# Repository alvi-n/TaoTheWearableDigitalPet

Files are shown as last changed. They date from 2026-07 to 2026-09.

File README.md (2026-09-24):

# Tao - A Palm-Sized, Sensor-Driven Dynamic Digital Pet ⭐

Tao is a highly responsive, accessible companion device that uses an **accelerometer** much like on phones that detect orientation to switch from portrait to landscape mode. It also utilizes a **temperature sensor** and **haptic motors** that vibrate, which all triggers unique face animations.

Over the past few months, I've been seeing this unique hardware accessory called ["Starboy" by CREATURE](https://hesjustalittleguy.com/). It features a palm-sized digital pet that has a star-shaped form factor and a round screen in the middle with very expressive eyes. As you can probably tell by the title description, this project was heavily inspired by this. I was immediately captivated by the concept, but with the original product selling for around $150 to $300, I thought it felt like a great open-source, diy project.
> _"STARBOY perceives its environment through a camera, microphone, temperature sensor, and accelerometer. bring him into a loud environment and he gets anxious. Leave him in the cold and he shivers. Shake him and he gets dizzy and mad at you. give him a thumbs up to check the battery level, or flick him off if you feel like making him sad."_

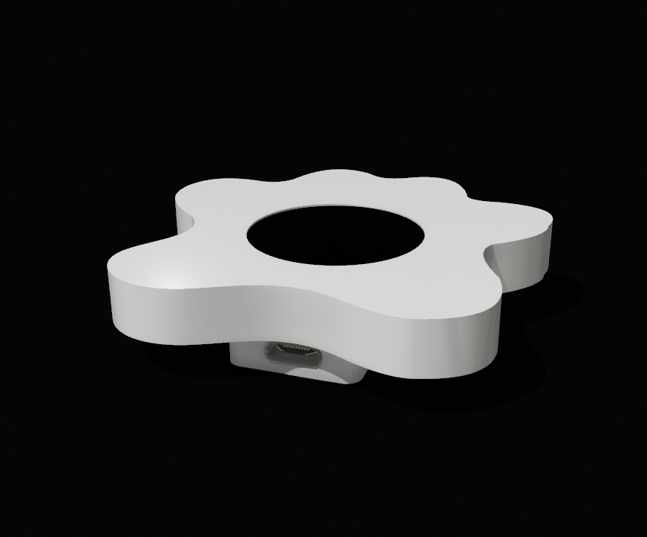
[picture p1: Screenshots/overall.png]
in cad

in my hand

## Hardware
- Seeed XIAO ESP32-S3
- Round GC9A01 SPI LCD
- LSM6DSL accelerometer (I2C)
- PCT2075D Temperature sensor (I2C)
- DRV2605L haptic driver (I2C, shared bus)
- 3.7V 300mAh LiPo battery

| Schematic | PCB | Render |
| ----- | ---- | ---- |
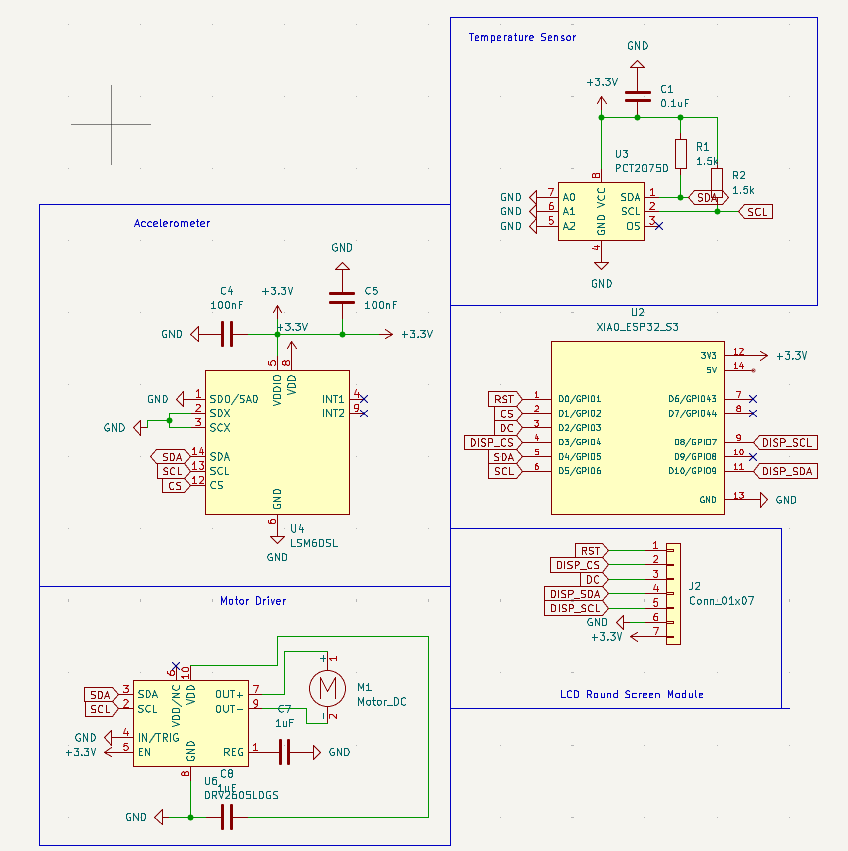
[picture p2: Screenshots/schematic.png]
"Schematic"
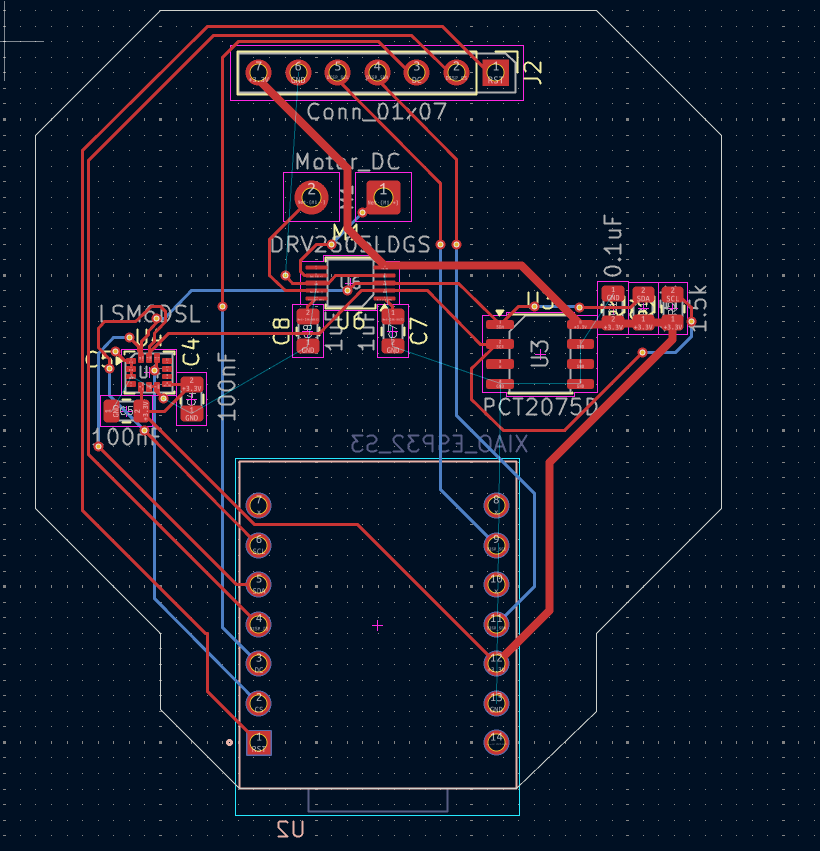
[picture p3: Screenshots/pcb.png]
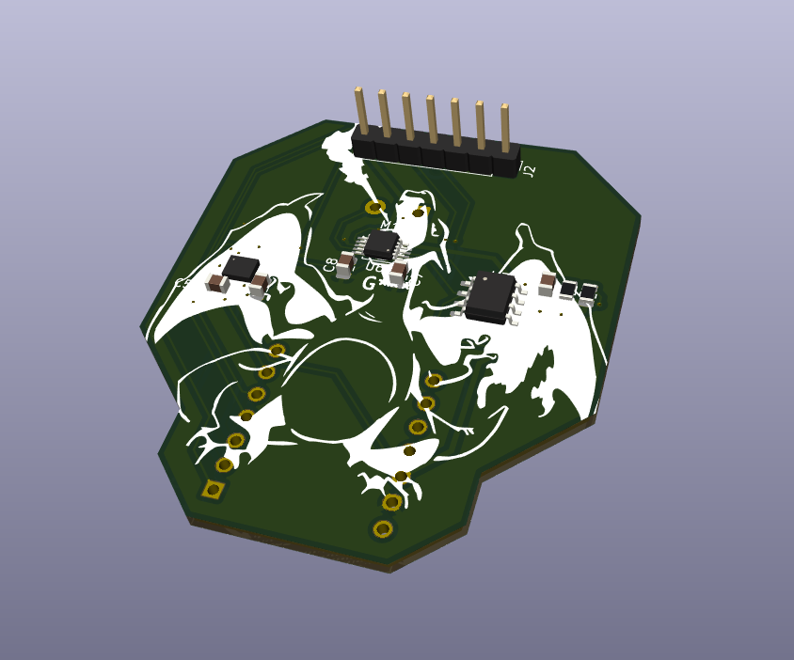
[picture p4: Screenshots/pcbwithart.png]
|  |  | 

## What It Does
- Two animated eyes are Tao's entire face
- An LSM6DSL accelerometer notes any change in motion in real time
  -The accelerometer reads the change in acceleration magnitude between frames and sorts it into still / moving / shake states
  - This is very similar to how your phone can detect if your screen is turned so you could watch videos fullscreen
- A haptic motor creates different unique haptic patterns depending on what Tao is going through
- Uses an ESP32-S3 development board to make power management easier

## Future Plans
- Add additional states for more interactions
- Use a deburring tool to round out all the edges
### If done again...
- NFC Chip - Originally this was supposed to have one but making a custom antenna was a diffcult process in such a limited space
- No modules - this means all power managment will have to be designed from scratch and same with the screen module
- Add more inputs like a microphone, camera, photoresistor, etc

BOM
| item | quantity | Link | Price |
| --- | --- | --- | --- |
| LSM6DSVQTR | 1 | lcsc | $12.04 |
| DRV2605LYZFR | 1 | lcsc | $6.75 |
| 10kΩ Resistor | 2 | lcsc | $0.03 |
| 100nF Capacitors | 4 | lscs | $0.34 |
| Seeed XIAO ESP32-S3 | 1 | https://www.seeedstudio.com/XIAO-ESP32S3-p-5627.html | $7.49 |
| 3.7V 300mAh 502035 LiPo | 1 | https://a.co/d/0aBGCeCJ | $9 |
| Round LCD Module GC9A01 | 1 | https://tinyurl.com/yj44nenv | $2 |
| LRA Haptic Motor| 1 | https://www.adafruit.com/product/1201 | $6 |
| PCT2075D Temperature Sensor| 1 | lcsc | $2.07 |
| Plastic Case | 3D - Printed |

> [!NOTE]
> Estimated Total Price: ~$75 USD with shipping 
> JLC PCBA charges an extra $21.77 for fees

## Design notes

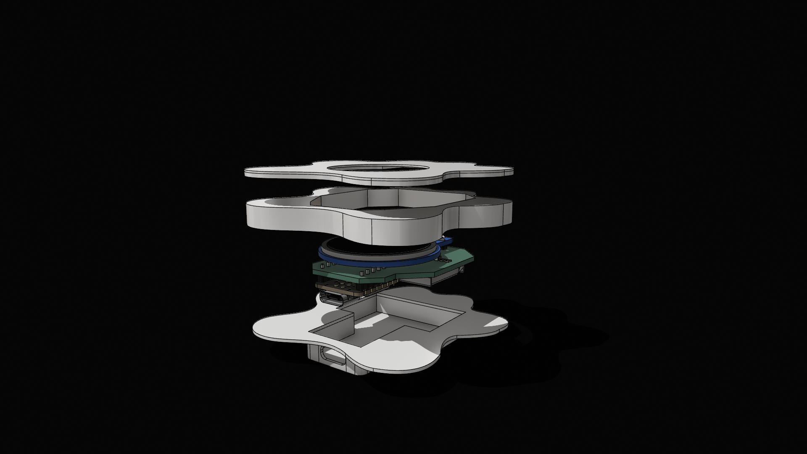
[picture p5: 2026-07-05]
Screenshots/fit.png

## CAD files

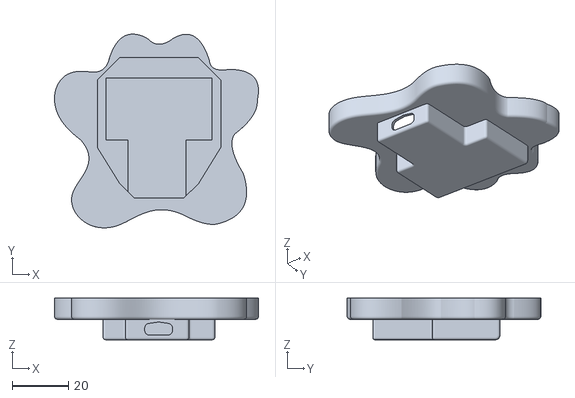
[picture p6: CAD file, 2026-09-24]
CAD/Folder 66.stl
72.7 x 69.0 x 14.8

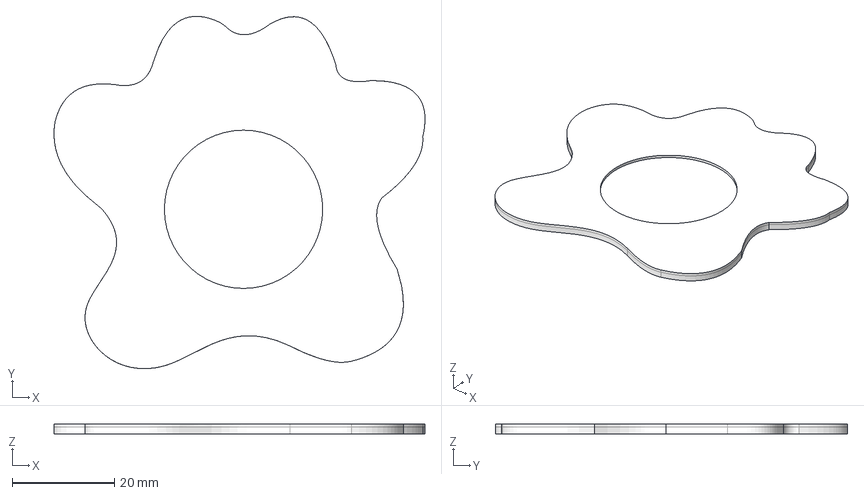
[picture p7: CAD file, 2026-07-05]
Production/topstar_v2.step
72.7 x 69.0 x 1.90 mm

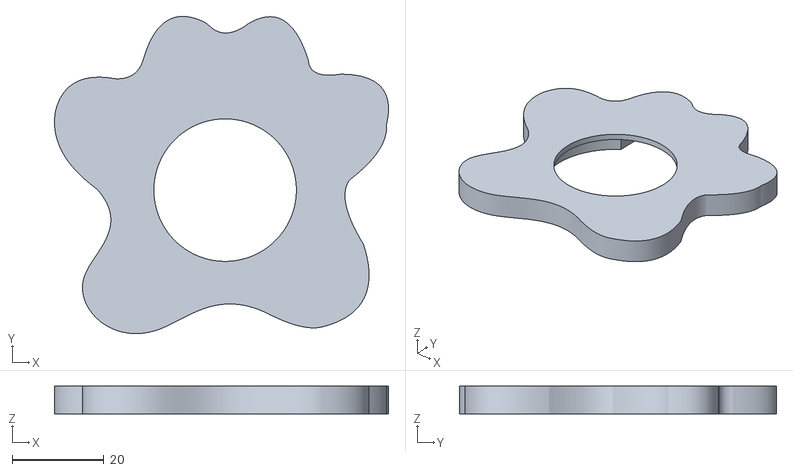
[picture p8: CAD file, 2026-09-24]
CAD/top_v2.stl
72.7 x 69.0 x 6.00

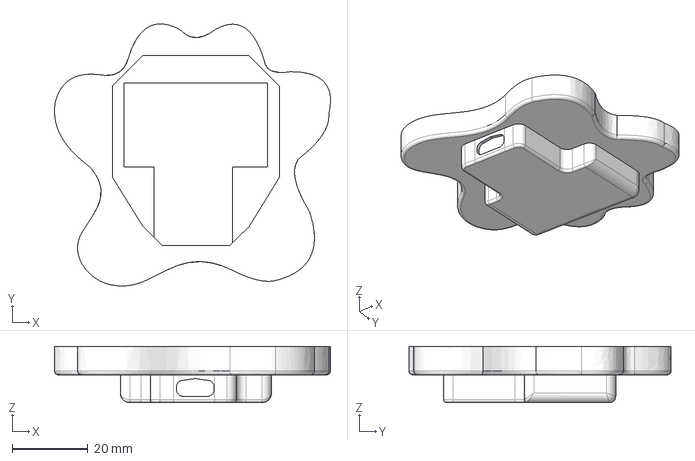
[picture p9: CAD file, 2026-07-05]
Production/bottomstar_v2.step
72.7 x 69.0 x 14.8 mm

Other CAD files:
Production/topstar.step

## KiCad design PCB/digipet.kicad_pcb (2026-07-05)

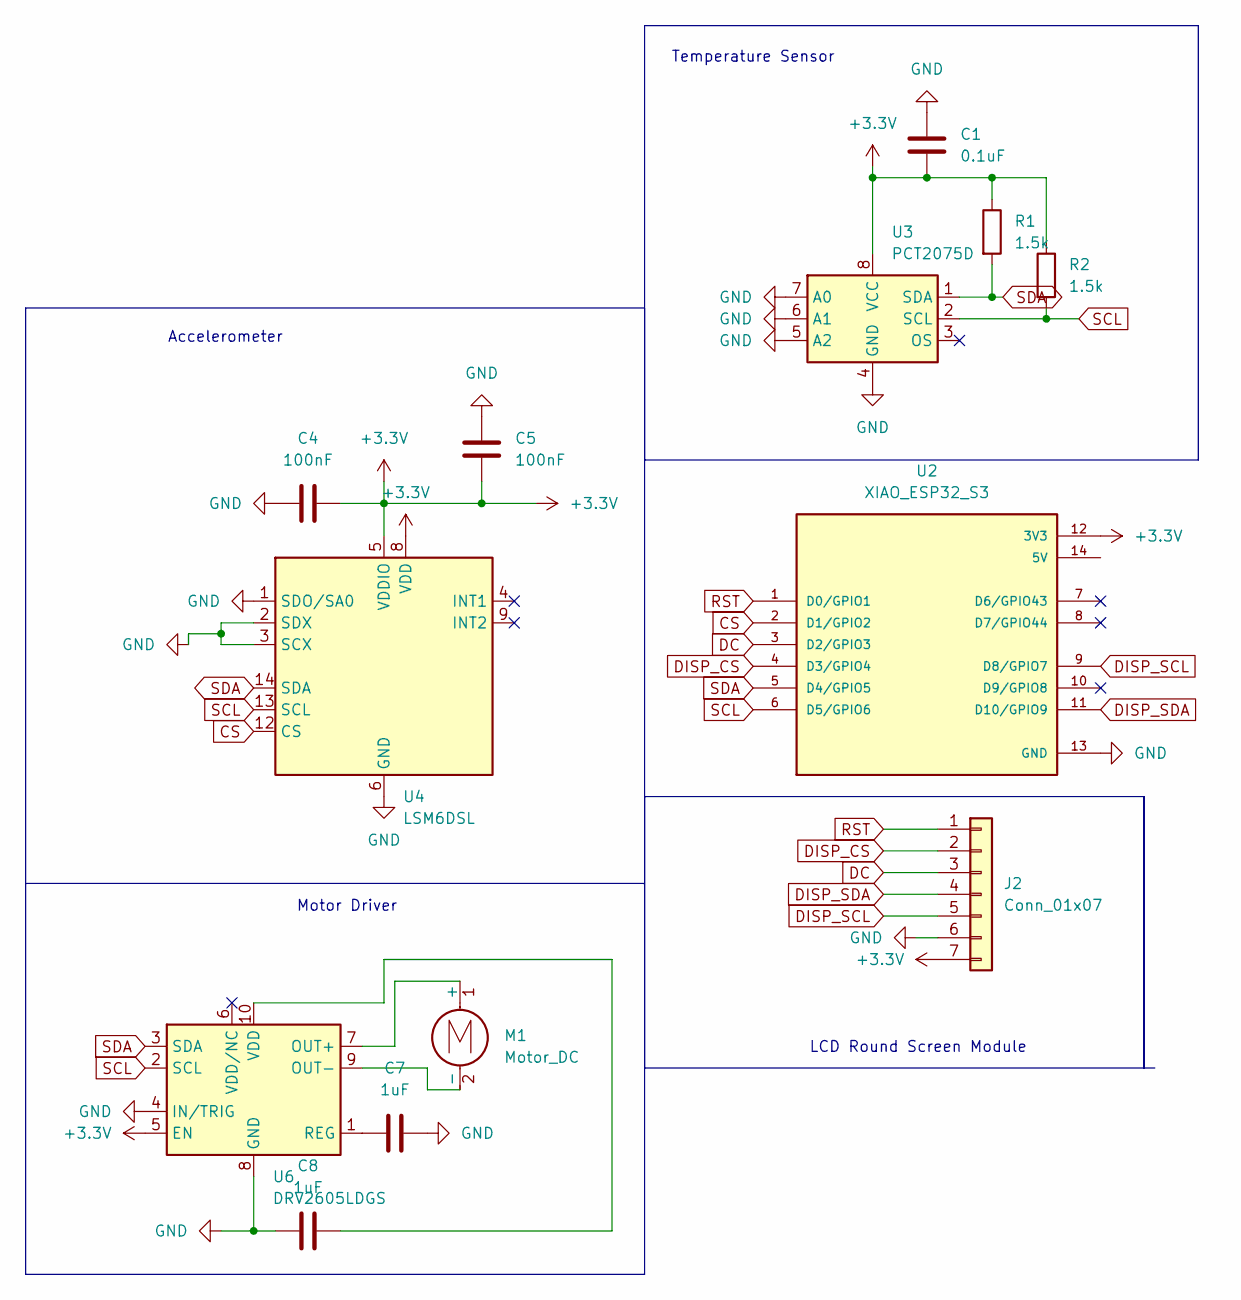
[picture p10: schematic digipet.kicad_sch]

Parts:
C1: 0.1uF; C_0805_2012Metric
C4, C5: 100nF; C_0805_2012Metric
C7, C8: 1uF; C_0805_2012Metric
J2: Conn_01x07; PinHeader_1x07_P2.54mm_Vertical
M1: Motor_DC; SolderWire-0.5sqmm_1x02_P4.6mm_D0.9mm_OD2.1mm
R1, R2: 1.5k; R_0805_2012Metric
U2: XIAO_ESP32_S3; MODULE_XIAO_ESP32_S3; PARTREV April 22nd, 2026
U3: PCT2075D; SO-8_3.9x4.9mm_P1.27mm
U4: LSM6DSL; LGA-14_3x2.5mm_P0.5mm_LayoutBorder3x4y
U6: DRV2605LDGS; VSSOP-10_3x3mm_P0.5mm

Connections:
+3.3V: C1.2, C4.2, C5.2, J2.7, R1.1, R2.1, U2.12 (3V3), U3.8 (VCC), U4.5 (VDDIO), U4.8 (VDD), U6.5 (EN)
CS: U2.2 (D1/GPIO2), U4.12 (CS)
DC: J2.3, U2.3 (D2/GPIO3)
DISP_CS: J2.2, U2.4 (D3/GPIO4)
DISP_SCL: J2.5, U2.9 (D8/GPIO7)
DISP_SDA: J2.4, U2.11 (D10/GPIO9)
GND: C1.1, C4.1, C5.1, C7.2, C8.1, J2.6, U2.13 (GND), U3.4 (GND), U3.5 (A2), U3.6 (A1), U3.7 (A0), U4.1 (SDO/SA0), U4.2 (SDX), U4.3 (SCX), U4.6 (GND), U4.7 (GND), U6.4 (IN/TRIG), U6.8 (GND)
unnamed: M1.1 (+), U6.7 (OUT+)
unnamed: M1.2 (-), U6.9 (OUT-)
unnamed: C7.1, U6.1 (REG)
unnamed: C8.2, U6.10 (VDD)
RST: J2.1, U2.1 (D0/GPIO1)
SCL: R2.2, U2.6 (D5/GPIO6), U3.2 (SCL), U4.13 (SCL), U6.2 (SCL)
SDA: R1.2, U2.5 (D4/GPIO5), U3.1 (SDA), U4.14 (SDA), U6.3 (SDA)

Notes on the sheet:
Motor Driver
Temperature Sensor
Accelerometer
LCD Round Screen Module

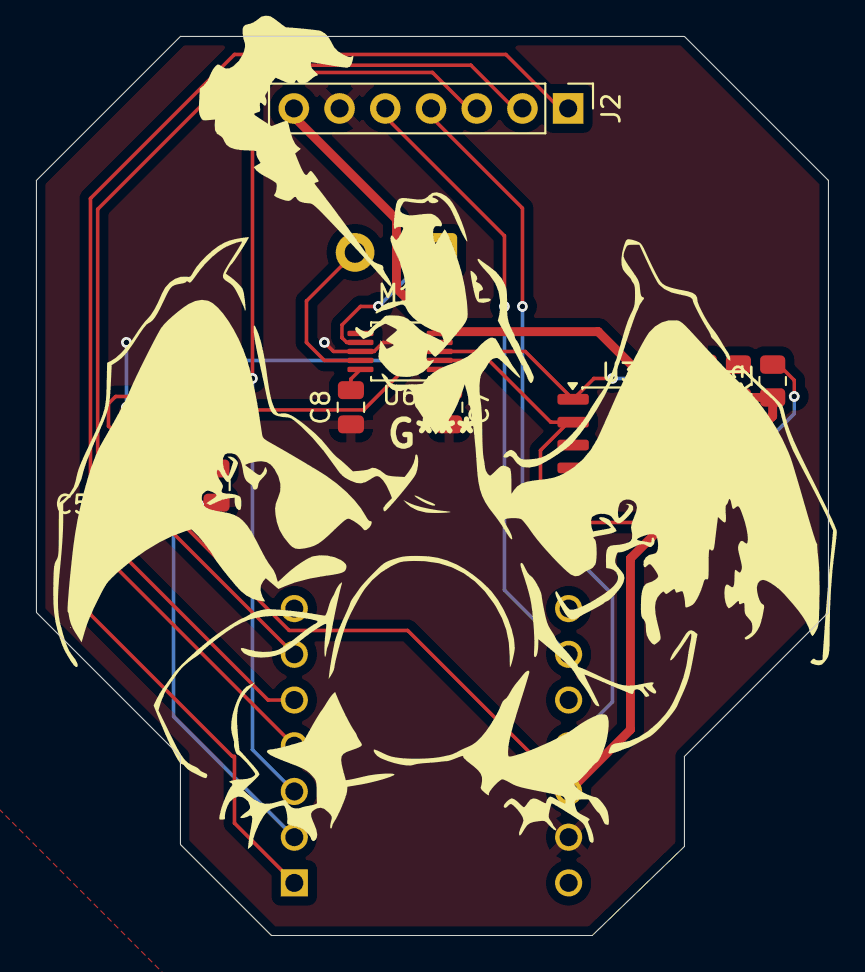
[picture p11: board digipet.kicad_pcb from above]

Board: 2 copper layers, 44.0 x 49.9 mm, 13 parts (1 on the bottom side), 14 nets.

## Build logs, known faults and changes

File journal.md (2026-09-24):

# Digital Pet PCB — Build Log

## No modules, everything on a PCB. *(1 hr)*

I've been seeing these digital pet accessories, similar to a Tamagotchi, on my feed a lot and the company selling these were listing them for ~$300 and I thought "I could definitely make this myself". These things interact with the environment with some basic sensors which gives the face a signal to change its animation.

Turns out it's wayy harder than I thought to make myself, considering my only hardware project I've made was a macropad.

There is a lot of pieces and I obviously haven't built anything like this ever. Instead of adding modules that hook up to a breadboard, I realized that all of those parts can be added to the PCB itself, and it all starts with the chip.

I looked for the best chip for each of the different features and looked at the schematic for each. The only chip with a datasheet that actually made sense was for the battery charger, the rest... it took a bit more work.

Anyways tomorrow, I'm planning on trying to finish the schematics, so make sure to follow!

<p align="center">
  
</p>

---

## Tao Now Has an Accelerometer, NFC Reader, and a Temperature Sensor *(2 hr 19 min)*

`all powered by the xiao esp-32 s3`

- I never realized how powerful **development boards** are. Last session, I took an hour trying to figure out how to make a buck converter, battery charger, and an external USB-C connector — turns out the XIAO board does all of that for me.
- Now instead of focusing my time on the power management side of my project, which was really confusing for me, I could now focus on adding additional **fun** elements to my project such as a haptic motor and temperature sensor.
- Overall this project has been pretty fun so far — next step is working on the PCB layout and thinking about the shape of my digital pet.

<p align="center">
  
</p>

---

## A little bit of this and a little bit of that. *(51 min)*

Today I started on my actual PCB design and turns out it's harder than I thought. My schematic is like a maze, some lines in my schematic going two directions. Figuring out the best way to put everything is definitely a challenge.

- Tomorrow, I'll start working on the edge cuts first and try to get 50% of the PCB wired.

<p align="center">
  
</p>

---

## Outlining my PCB *(30 min)*

Not much was done in these 30 minutes, just imported a drawing of the shape of the pet.

<p align="center">
  
  
</p>

---

## PCB routing - continued *(1 hr 21 min)*

So far I believe I've set up the temperature sensor, motor driver, and accelerometer well — and by that, I mean just the capacitors and resistors.

I'm planning on putting the ESP32 on the back side where I'll also keep the battery so it doesn't interfere with the LCD screen. This has been quite fun so far.

<p align="center">
  
</p>

---

## Honestly, I do not think I can get past the cut *(3 hr 6 min)*

Spent too long trying to figure out how to make my own NFC chip antenna, and for the time I'm trying to rush this project, I don't think I can.

- I think I will end up using a module with header pins for it instead of making it myself. It's really devastating, but for the sake of maintaining my enjoyment throughout this project I'm going to lower my scope.

<p align="center">
  
</p>

---

## Taking out the NFC, Retracing Everything *(1 hr 58 min)*

This took a little too long. Turns out since I didn't have an LCD screen footprint, I didn't really know where the middle of the screen would be relative to the rest of the PCB. When I put everything into my 3D modeling software (Shapr3D), I realized it would be better if the screen was directly in the middle of the PCB by making it vertical — which ultimately means I have to retrace almost everything.

<p align="center">
  
</p>

---

## Time skip - I finished all the CAD and code for the project and I think it's about time to submit! *(1 hr 15 min)*

- I added a Charizard silkscreen design and it looks pretty cool.
- The case has a pretty big back for the battery, but I guess it's not too noticeable.
- The main thing I'm not too sure about is the schematic and PCB wiring, but hopefully if the design comes back for a redo I can do that fast.
- This was a really fun project and I'm surprised myself — I was able to remain consistent with this project.

<p align="center">
  pcbwithart
  fit
</p>

## Parts shipped! - Changing the cad *(45 min)*

- After getting my parts I 3D-printed the model I originally made, of course, it was too tight or too loose on some ends.
- A bit of adjustments later and two iterations, I finally got a case I like. It's a bit chunky but it looks good nevertheless.
- 



## Solder time - Soldered parts while my case was printing *(1 hr 15 min)*

- It was way easier than last time trying to solder a macropad. I think after going to a hardware hackathon over the summer, my soldering skills definitely improved.
- The process is first solder on the microcontroller --> then the haptic motor --> then the screen --> then the battery 



## Finished product *(2 hr)*

- Took way too much time readjusting the code, redoing it, compiling it, realizing it doesn't work, again.
- After a bit, I just wanted to get the core features down such as:
1. Eye movement when I tilt
2. Dizzy animation when I shake it
3. Animation when I drop it (when g-force = 0)
4. Sleep animation when left alone



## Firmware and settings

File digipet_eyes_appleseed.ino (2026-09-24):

// digipet_eyes_simple.ino
// Simple friendly black/white circle eyes with pupils, on Adafruit_GC9A01A
// (the stack that actually works - no LVGL/TFT_eSPI).
//
// Shake animation: while shaking, eyes scroll straight down and wrap back in
// from the top (like a slot-machine reel) - reads as spinning, no rotation
// math needed. When the shake stops, eyes glide smoothly back to their
// resting spot instead of snapping.
//
// Arduino Library Manager:
//   Adafruit GFX Library
//   Adafruit GC9A01A  (pulls in Adafruit BusIO)
//
// Board: XIAO_ESP32S3   Serial: 115200
//
// J2 (square pad = pin 1):
//   1 RST   2 CS   3 DC   4 SDA/MOSI   5 SCL/SCK   6 GND   7 3V3

enum FaceMood { FACE_LOOK, FACE_DIZZY, FACE_SURPRISE, FACE_FREEFALL, FACE_SLEEPY, FACE_UPSIDE };

#include <Wire.h>
#include <SPI.h>
#include <Adafruit_GFX.h>
#include <Adafruit_GC9A01A.h>
#include <math.h>

static const int PIN_IMU_CS = D1;
static const int PIN_TFT_DC = D2;
static const int PIN_TFT_CS = D3;
static const int PIN_TFT_RST = D0;
static const int PIN_TFT_SCK = D8;
static const int PIN_TFT_MOSI = D10;

static const uint8_t ADDR_LSM6_LOW = 0x6A;
static const uint8_t ADDR_LSM6_HIGH = 0x6B;
static const uint8_t LSM6_WHO_AM_I = 0x0F;
static const uint8_t LSM6_CTRL1 = 0x10;
static const uint8_t LSM6_CTRL2 = 0x11;
static const uint8_t LSM6_CTRL3 = 0x12;
static const uint8_t LSM6_CTRL8 = 0x17;
static const uint8_t LSM6_OUTX_L_G = 0x22;
static const uint8_t LSM6_CTRL3_BDU_INC = 0x44;
static const uint8_t LSM6_ODR_60HZ = 0x05;
static const uint8_t LSM6_CTRL8_4G = 0x01;
static const float ACCEL_G_PER_LSB = 0.000122f;
static const float GYRO_DPS_PER_LSB = 0.00875f;

static const float SX_FROM_AX = -1.0f;
static const float SY_FROM_AY = -1.0f;

Adafruit_GC9A01A tft(PIN_TFT_CS, PIN_TFT_DC, PIN_TFT_RST);
GFXcanvas16 canvas(240, 240);

// ---- Eye shape ----
static const int EYE_R = 38;     // main white circle radius
static const int PUPIL_R = 15;   // black pupil radius
static const int EYE_DX = 44;    // horizontal distance from center
static const int EYE_CY = 118;   // resting vertical position (screen center-ish)

// ---- Dizzy scroll-wrap animation ----
static const float DIZZY_SCROLL_SPEED = 260.0f; // px/sec, downward
static const uint32_t SETTLE_DURATION_MS = 450;  // how long the smooth glide-back takes

// ---- Sensitivity tuning ----
static const float GYRO_DIZZY_THRESHOLD = 420.0f;
static const uint32_t GYRO_SUSTAIN_MS = 180;
static const float ACCEL_SURPRISE_DELTA = 2.0f;
static const float ACCEL_FREEFALL_G = 0.35f;

uint8_t imuAddr = 0;
bool imuReady = false;

bool i2cWrite8(uint8_t addr, uint8_t reg, uint8_t value) {
  Wire.beginTransmission(addr);
  Wire.write(reg);
  Wire.write(value);
  return Wire.endTransmission() == 0;
}

bool i2cReadBytes(uint8_t addr, uint8_t reg, uint8_t *buf, uint8_t len) {
  Wire.beginTransmission(addr);
  Wire.write(reg);
  if (Wire.endTransmission(false) != 0) return false;
  if (Wire.requestFrom(addr, len) != len) return false;
  for (uint8_t i = 0; i < len; i++) buf[i] = Wire.read();
  return true;
}

bool probeImu(uint8_t addr, uint8_t *whoami) {
  return i2cReadBytes(addr, LSM6_WHO_AM_I, whoami, 1);
}

bool initImu() {
  pinMode(PIN_IMU_CS, OUTPUT);
  digitalWrite(PIN_IMU_CS, HIGH);
  delay(10);

  Wire.begin(D4, D5);
  Wire.setClock(400000);
  delay(20);

  uint8_t who = 0;
  uint8_t addrs[] = {ADDR_LSM6_LOW, ADDR_LSM6_HIGH};
  for (uint8_t i = 0; i < 2; i++) {
    if (!probeImu(addrs[i], &who)) continue;
    imuAddr = addrs[i];
    Serial.print(F("IMU WHO_AM_I @ 0x"));
    Serial.print(imuAddr, HEX);
    Serial.print(F(" = 0x"));
    Serial.println(who, HEX);
    i2cWrite8(imuAddr, LSM6_CTRL3, LSM6_CTRL3_BDU_INC);
    i2cWrite8(imuAddr, LSM6_CTRL8, LSM6_CTRL8_4G);
    i2cWrite8(imuAddr, LSM6_CTRL1, LSM6_ODR_60HZ);
    i2cWrite8(imuAddr, LSM6_CTRL2, LSM6_ODR_60HZ);
    delay(20);
    return true;
  }
  Serial.println(F("IMU not found on D4/D5. Trying D9/D8..."));
  Wire.end();
  Wire.begin(D9, D8);
  Wire.setClock(400000);
  delay(20);
  for (uint8_t i = 0; i < 2; i++) {
    if (!probeImu(addrs[i], &who)) continue;
    imuAddr = addrs[i];
    i2cWrite8(imuAddr, LSM6_CTRL3, LSM6_CTRL3_BDU_INC);
    i2cWrite8(imuAddr, LSM6_CTRL8, LSM6_CTRL8_4G);
    i2cWrite8(imuAddr, LSM6_CTRL1, LSM6_ODR_60HZ);
    i2cWrite8(imuAddr, LSM6_CTRL2, LSM6_ODR_60HZ);
    Serial.println(F("IMU found on D9/D8"));
    return true;
  }
  return false;
}

bool readImu(float *ax, float *ay, float *az, float *gx, float *gy, float *gz) {
  uint8_t raw[12];
  if (!i2cReadBytes(imuAddr, LSM6_OUTX_L_G, raw, 12)) return false;
  auto s16 = [](uint8_t lo, uint8_t hi) -> int16_t {
    return (int16_t)((uint16_t)hi << 8 | lo);
  };
  *gx = s16(raw[0], raw[1]) * GYRO_DPS_PER_LSB;
  *gy = s16(raw[2], raw[3]) * GYRO_DPS_PER_LSB;
  *gz = s16(raw[4], raw[5]) * GYRO_DPS_PER_LSB;
  *ax = s16(raw[6], raw[7]) * ACCEL_G_PER_LSB;
  *ay = s16(raw[8], raw[9]) * ACCEL_G_PER_LSB;
  *az = s16(raw[10], raw[11]) * ACCEL_G_PER_LSB;
  return true;
}

// ---- Drawing helpers ----

float smoothlerp(float a, float b, float t) {
  return a + (b - a) * t;
}

float smoothstep01(float t) {
  if (t < 0) t = 0;
  if (t > 1) t = 1;
  return t * t * (3.0f - 2.0f * t);
}

void fillEllipse(int cx, int cy, int rx, int ry, uint16_t color) {
  if (rx < 1) rx = 1;
  if (ry < 1) ry = 1;
  for (int y = -ry; y <= ry; y++) {
    float ny = (float)y / (float)ry;
    int xspan = (int)(rx * sqrtf(1.0f - ny * ny) + 0.5f);
    canvas.drawFastHLine(cx - xspan, cy + y, xspan * 2 + 1, color);
  }
}

// Draws one eye: white circle (squashed vertically for blinking), black pupil
// offset inside it for gaze.
void drawEye(int cx, int cy, float openScale, float pupilOffX, float pupilOffY, float pupilScale) {
  int ry = (int)(EYE_R * openScale);
  if (ry < 3) ry = 3;
  fillEllipse(cx, cy, EYE_R, ry, GC9A01A_WHITE);

  if (openScale < 0.2f) return; // eye closed - no pupil to show

  int maxOffX = EYE_R - (int)(PUPIL_R * pupilScale) - 4;
  int maxOffY = ry - (int)(PUPIL_R * pupilScale) - 4;
  if (maxOffX < 2) maxOffX = 2;
  if (maxOffY < 2) maxOffY = 2;
  int px = cx + (int)(constrain(pupilOffX, -1.0f, 1.0f) * maxOffX);
  int py = cy + (int)(constrain(pupilOffY, -1.0f, 1.0f) * maxOffY);
  int pr = (int)(PUPIL_R * pupilScale);
  if (pr < 3) pr = 3;
  canvas.fillCircle(px, py, pr, GC9A01A_BLACK);
}

const char *moodName(FaceMood m) {
  switch (m) {
    case FACE_DIZZY: return "DIZZY";
    case FACE_SURPRISE: return "SURPRISE";
    case FACE_FREEFALL: return "FREEFALL";
    case FACE_SLEEPY: return "SLEEPY";
    case FACE_UPSIDE: return "UPSIDE";
    default: return "LOOK";
  }
}

FaceMood mood = FACE_LOOK, lastMood = FACE_LOOK;

uint32_t dizzyUntil = 0, dizzySustainStart = 0, surpriseUntil = 0, freefallUntil = 0;
uint32_t stillSince = 0, nextBlinkAt = 0, blinkUntil = 0;
float openAmt = 1.0f;
float pupilOffX = 0, pupilOffY = 0, pupilScale = 1.0f;

float dizzyScrollY = 0;
bool settling = false;
uint32_t settleStart = 0;
float settleFromY = EYE_CY;
float currentEyeY = EYE_CY;

uint32_t lastMs = 0;

void setup() {
  Serial.begin(115200);
  delay(200);
  Serial.println(F("Simple eyes"));

  SPI.begin(PIN_TFT_SCK, -1, PIN_TFT_MOSI, PIN_TFT_CS);
  tft.begin(40000000);
  tft.setRotation(0);

  canvas.fillScreen(GC9A01A_BLACK);
  drawEye(120 - EYE_DX, EYE_CY, 1.0f, 0, 0, 1.0f);
  drawEye(120 + EYE_DX, EYE_CY, 1.0f, 0, 0, 1.0f);
  tft.drawRGBBitmap(0, 0, canvas.getBuffer(), 240, 240);
  Serial.println(F("Display up"));

  imuReady = initImu();
  if (imuReady) Serial.println(F("IMU OK"));
  else Serial.println(F("IMU missing — idle blink only"));

  lastMs = millis();
  stillSince = lastMs;
  nextBlinkAt = lastMs + 1800;
}

void loop() {
  float ax = 0, ay = 0, az = 1, gx = 0, gy = 0, gz = 0;
  if (imuReady && !readImu(&ax, &ay, &az, &gx, &gy, &gz)) {
    ax = 0; ay = 0; az = 1;
  }

  uint32_t now = millis();
  float dt = (now - lastMs) / 1000.0f;
  lastMs = now;
  if (dt <= 0 || dt > 0.2f) dt = 0.02f;

  float sx = SX_FROM_AX * ax;
  float sy = SY_FROM_AY * ay;
  float gyroMag = sqrtf(gx * gx + gy * gy + gz * gz);
  float aMag = sqrtf(ax * ax + ay * ay + az * az);

  if (gyroMag > GYRO_DIZZY_THRESHOLD) {
    if (dizzySustainStart == 0) dizzySustainStart = now;
    if (now - dizzySustainStart > GYRO_SUSTAIN_MS) dizzyUntil = now + 1200;
  } else {
    dizzySustainStart = 0;
  }

  if (fabsf(aMag - 1.0f) > ACCEL_SURPRISE_DELTA && gyroMag < 160.0f) surpriseUntil = now + 450;
  if (aMag < ACCEL_FREEFALL_G) freefallUntil = now + 500;

  bool still = (gyroMag < 18.0f && fabsf(sx) < 0.18f && fabsf(sy) < 0.18f);
  if (still) { if (stillSince == 0) stillSince = now; } else { stillSince = now; }

  FaceMood prevMood = mood;
  if (now < freefallUntil) mood = FACE_FREEFALL;
  else if (now < dizzyUntil) mood = FACE_DIZZY;
  else if (now < surpriseUntil) mood = FACE_SURPRISE;
  else if (az < -0.35f) mood = FACE_UPSIDE;
  else if (now - stillSince > 3500) mood = FACE_SLEEPY;
  else mood = FACE_LOOK;

  if (mood != lastMood) {
    Serial.println(moodName(mood));
    lastMood = mood;
  }

  // ---- Dizzy just ended: start the smooth glide back to resting position ----
  if (prevMood == FACE_DIZZY && mood != FACE_DIZZY) {
    settling = true;
    settleStart = now;
    settleFromY = currentEyeY;
  }

  float tOpen = 1.0f;
  float tPupilX = 0, tPupilY = 0, tPupilScale = 1.0f;

  float tLookX = constrain(sx * 1.6f, -1.0f, 1.0f);
  float tLookY = constrain(sy * 1.6f, -1.0f, 1.0f);

  if (mood == FACE_DIZZY) {
    // ---- Scroll eyes straight down, wrapping back in from the top ----
    dizzyScrollY += DIZZY_SCROLL_SPEED * dt;
    float wrapRange = 240.0f + 2 * EYE_R;
    float wrapped = fmodf(dizzyScrollY, wrapRange) - EYE_R;
    currentEyeY = wrapped;
    tOpen = 1.0f;
    tPupilScale = 0.7f;
  } else if (settling) {
    float t = (now - settleStart) / (float)SETTLE_DURATION_MS;
    if (t >= 1.0f) {
      settling = false;
      currentEyeY = EYE_CY;
    } else {
      currentEyeY = smoothlerp(settleFromY, EYE_CY, smoothstep01(t));
    }
  } else {
    dizzyScrollY = 0;
    currentEyeY = EYE_CY;
  }

  if (mood == FACE_SURPRISE) {
    tOpen = 1.15f;
    tPupilScale = 0.5f;
  } else if (mood == FACE_FREEFALL) {
    tOpen = 1.2f;
    tPupilScale = 0.5f;
  } else if (mood == FACE_SLEEPY) {
    tOpen = 0.25f;
    tPupilY = 0.5f;
  } else if (mood == FACE_UPSIDE) {
    tOpen = 1.0f;
    tPupilY = -0.6f; // pupils look "up" since the device is flipped
  } else if (mood == FACE_LOOK && !settling) {
    tPupilX = tLookX;
    tPupilY = tLookY;
    if (now > nextBlinkAt && blinkUntil == 0) {
      blinkUntil = now + 120;
      nextBlinkAt = now + 1600 + (now % 2200);
    }
  }

  if (now < blinkUntil && mood != FACE_DIZZY) {
    tOpen = 0.06f;
  } else if (now >= blinkUntil) {
    blinkUntil = 0;
  }

  openAmt = smoothlerp(openAmt, tOpen, 0.3f);
  pupilOffX = smoothlerp(pupilOffX, tPupilX, 0.25f);
  pupilOffY = smoothlerp(pupilOffY, tPupilY, 0.25f);
  pupilScale = smoothlerp(pupilScale, tPupilScale, 0.25f);

  canvas.fillScreen(GC9A01A_BLACK);
  drawEye(120 - EYE_DX, currentEyeY, openAmt, pupilOffX, pupilOffY, pupilScale);
  drawEye(120 + EYE_DX, currentEyeY, openAmt, pupilOffX, pupilOffY, pupilScale);
  tft.drawRGBBitmap(0, 0, canvas.getBuffer(), 240, 240);
}

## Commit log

2026-07-05 Add KiCad PCB/CAD files
    [bottomstar.step, digipet.kicad_pcb, digipet.kicad_sch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]
2026-07-05 Changed CAD Design
    [bottomstar.step, bottomstar_v2.step, topstar_v2.step]
2026-07-08 added BOM.md
2026-09-24 added top and bottom shell
    [Folder 66.stl, top_v2.stl]
